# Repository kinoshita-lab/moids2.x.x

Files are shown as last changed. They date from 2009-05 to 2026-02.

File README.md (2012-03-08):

# About
These files are schematics, frame designs, and source codes for an artwork "moids 2.*.*".
You need at least arduino(pro, nano, duemilanove, etc.) or some alternatives to run this program.
We have confirmed this program works on Arduino-1.0 version so far.

When you want to know more about moids, please visit our website or watch video on youtube.

- http://www.moids.org/
- http://www.youtube.com/watch?v=-VmGS8YM7mo

# Instructions

1. get sources

   - git clone https://github.com/kinoshita-lab/moids-app.git

2. connect some devices, referring to the schematics

3. start Arduino environment, open moids_arduino.ino, verify and upload to I/O board.

4. repeat step 2 and 3 more than 400 times.

# Lisence

MsTimer2 library is a work by Javier Valencia, and has LGPL Lisence.

The others are completely public domain, 
You can modify, distribute as you like.

saita[at]kinoshita-lab.org

---
Kinoshita-lab 2009-2012

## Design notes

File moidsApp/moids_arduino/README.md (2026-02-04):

use arduino IDE with: 
Arduino Pro 3.3V 8MHz

pins

- LED 6, 9, 10
- Relay 4, 7, 8
- Mic A0, A1, A2

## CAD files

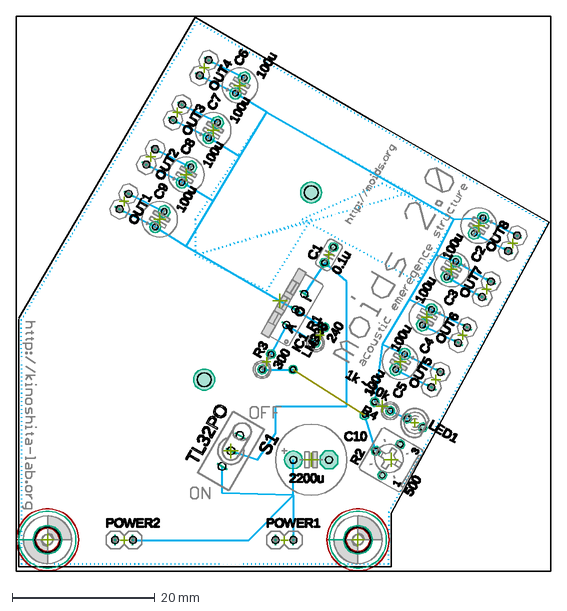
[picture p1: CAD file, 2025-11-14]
schematics/2025_power/graphics/moids2_0.1power_board_ほぼ原寸_all.dxf
75.0 x 77.9 mm

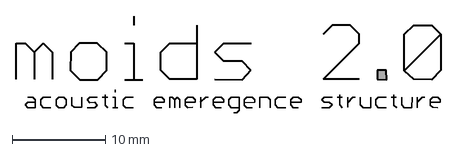
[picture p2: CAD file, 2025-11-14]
schematics/2025_power/moids2_0_text.dxf
45.4 x 10.3 mm

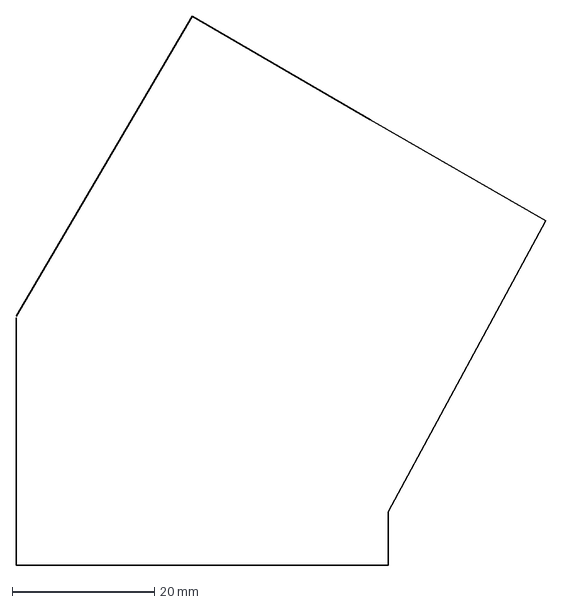
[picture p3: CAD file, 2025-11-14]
schematics/2025_power/graphics/moids2_0.1power_board_ほぼ原寸_edge_cuts.dxf
74.4 x 77.1 mm

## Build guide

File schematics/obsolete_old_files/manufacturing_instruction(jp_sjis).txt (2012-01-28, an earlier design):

moids2_0.1power.cmp(部品面パターンデータ)
moids2_0.1power.gpi（レポートファイル)
moids2_0.1power.plc（部品面シルクデータ）
moids2_0.1power.sol（半田面パターンデータ）
moids2_0.1power.stc（部品面レジストデータ）
moids2_0.1power.sts（半田面レジストデータ）
moids2_0.1power.out（外形線データ）

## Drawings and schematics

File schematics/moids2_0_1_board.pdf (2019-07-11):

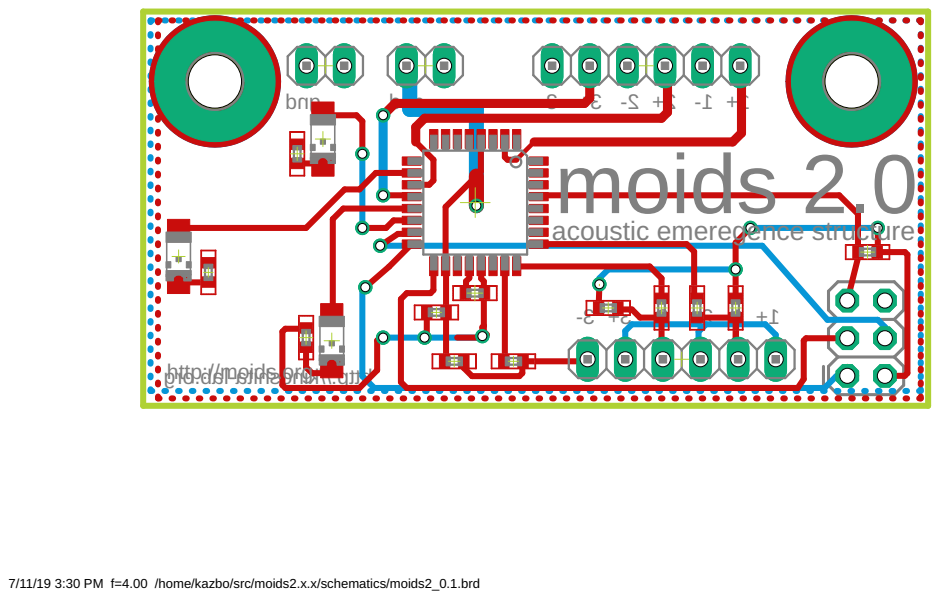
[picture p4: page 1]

7/11/19 3:30 PM f=4.00 /home/kazbo/src/moids2.x.x/schematics/moids2_0.1.brd

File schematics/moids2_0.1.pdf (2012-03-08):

# Moids 2.x Main Circuit

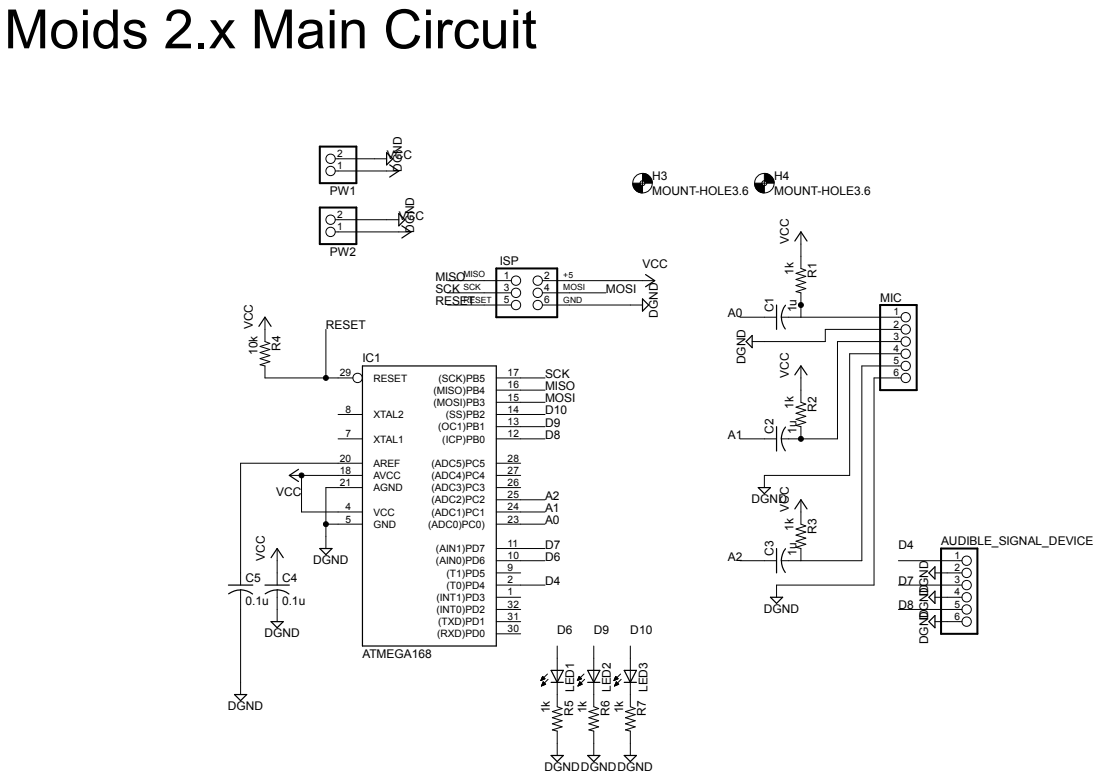
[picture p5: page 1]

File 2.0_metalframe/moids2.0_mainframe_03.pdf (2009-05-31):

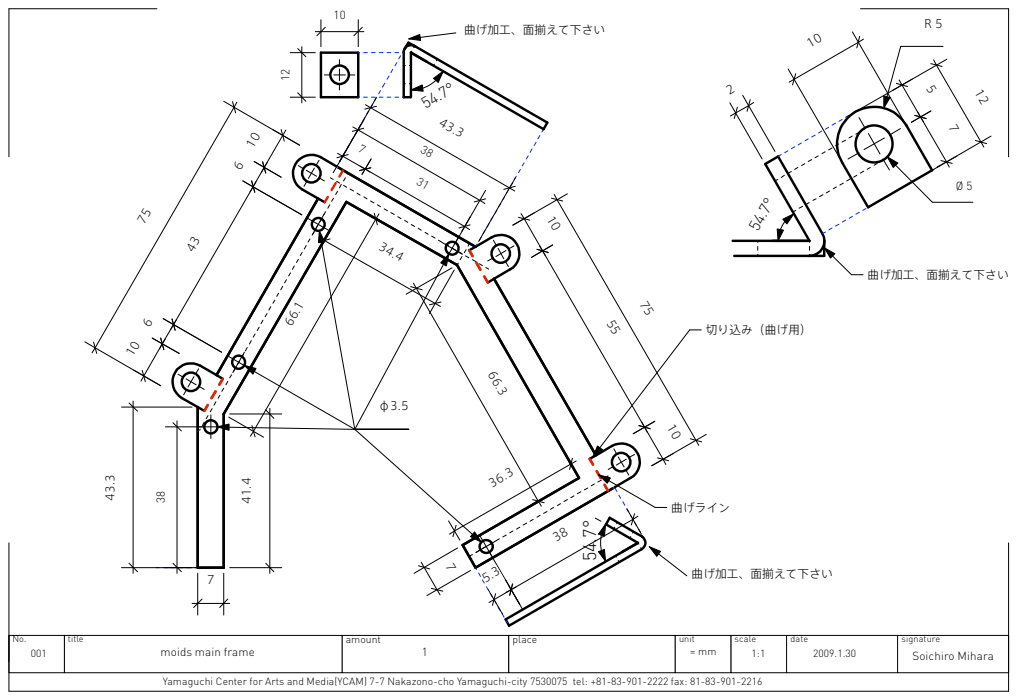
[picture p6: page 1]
title; amount; place; unit; scale; date; signature; Soichiro Mihara moids main frame; 曲げライン; 切り込み（曲げ用）; 曲げ加工、面揃えて下さい

Yamaguchi Center for Arts and Media(YCAM) 7-7 Nakazono-cho Yamaguchi-city 7530075 tel: +81-83-901-2222 fax: 81-83-901-2216

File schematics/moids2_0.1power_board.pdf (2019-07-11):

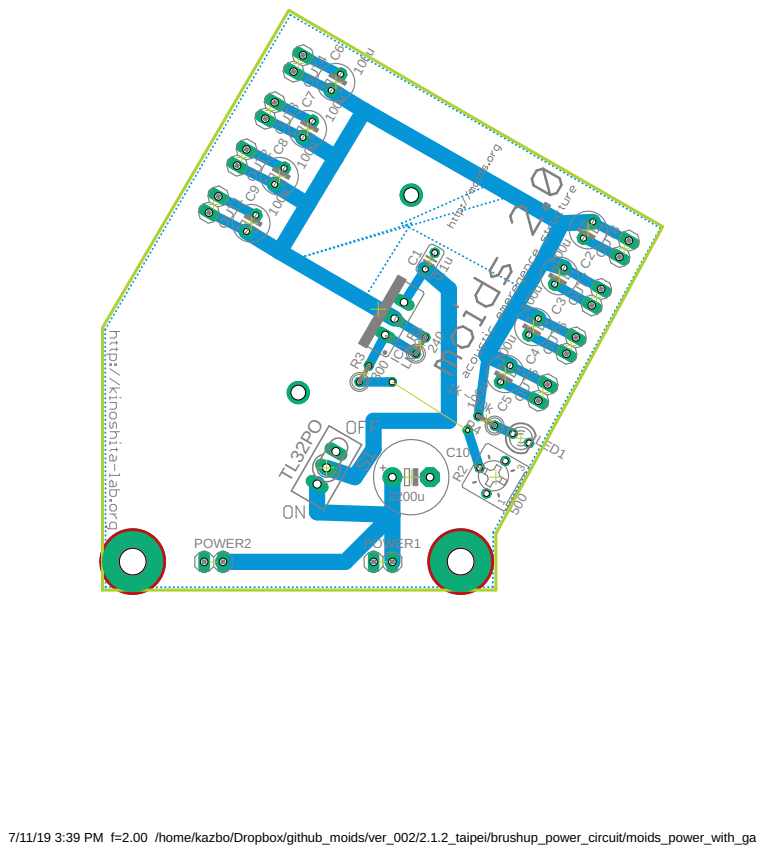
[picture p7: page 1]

7/11/19 3:39 PM f=2.00 /home/kazbo/Dropbox/github_moids/ver_002/2.1.2_taipei/brushup_power_circuit/moids_power_with_garbar/moids2_0.1power.brd

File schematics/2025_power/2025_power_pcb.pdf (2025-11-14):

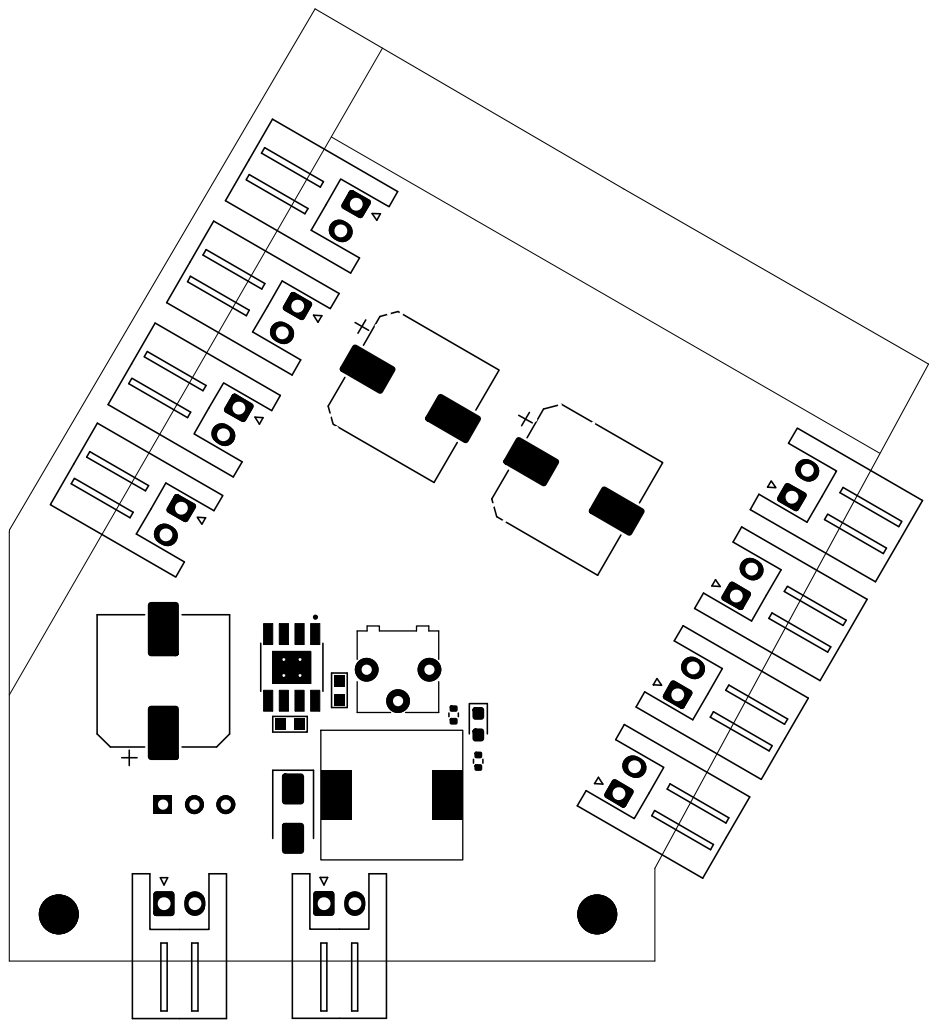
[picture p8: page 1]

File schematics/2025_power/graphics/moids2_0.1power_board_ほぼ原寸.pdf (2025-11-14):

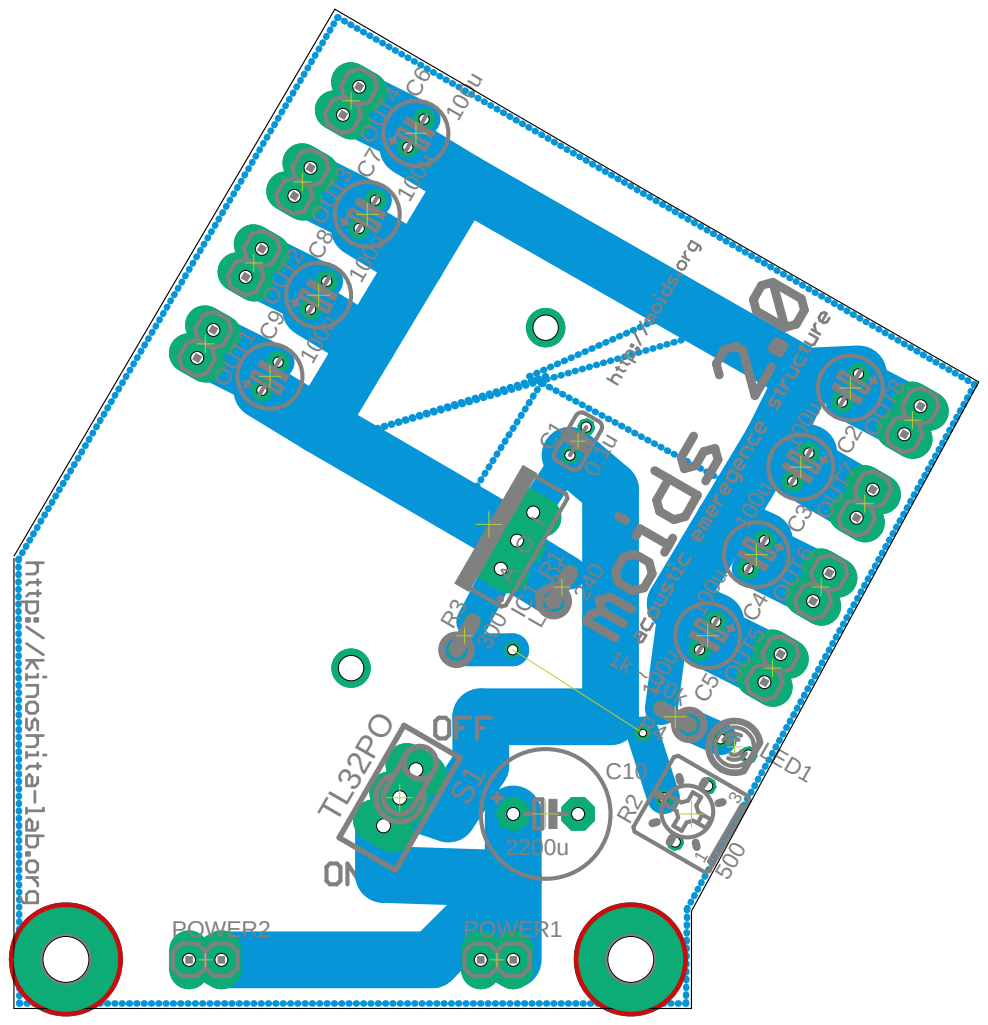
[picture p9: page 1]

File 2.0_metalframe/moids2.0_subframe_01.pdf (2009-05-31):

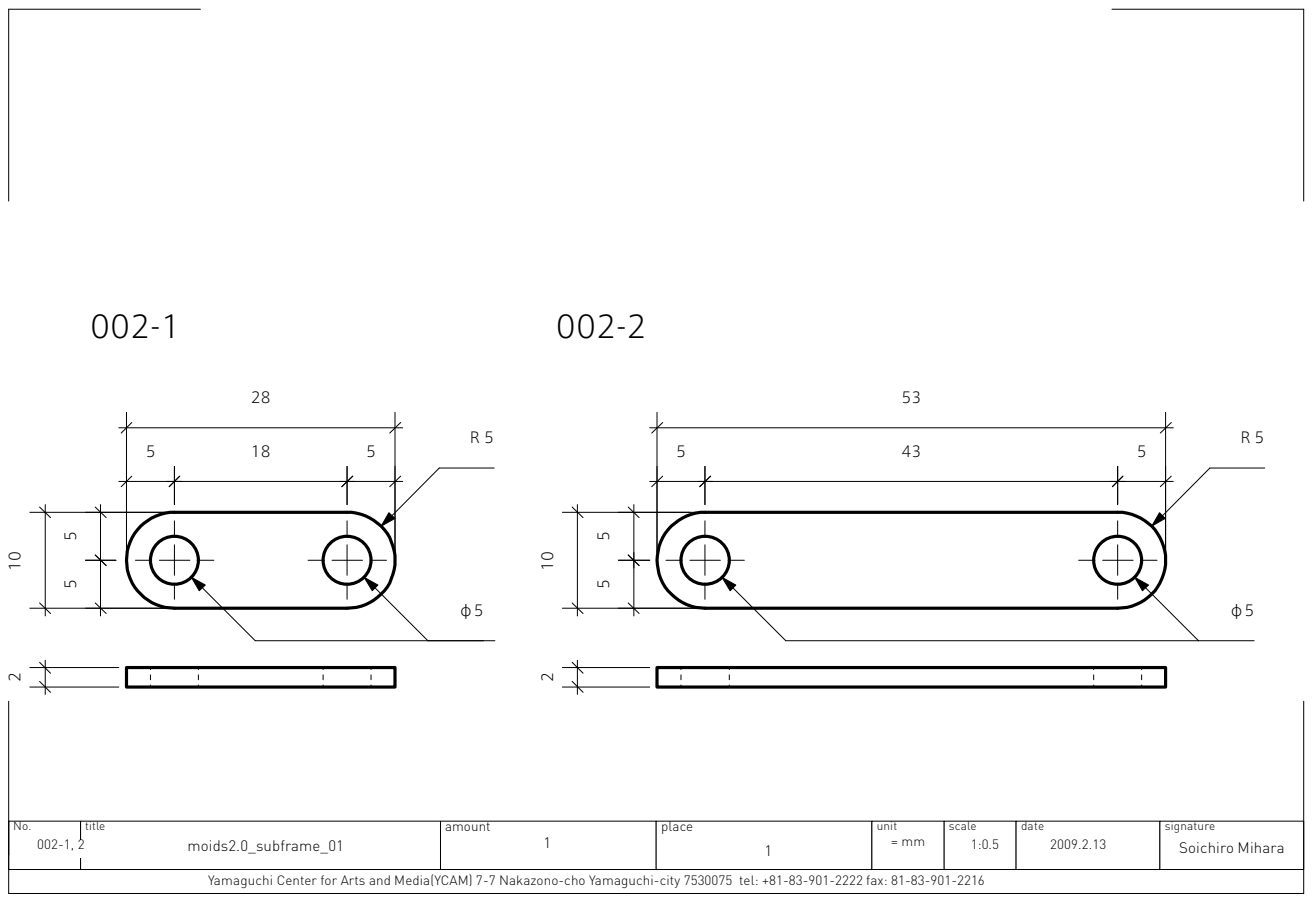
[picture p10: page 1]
title; amount; place; unit; scale; date; signature; Soichiro Mihara moids2.0_subframe_01

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

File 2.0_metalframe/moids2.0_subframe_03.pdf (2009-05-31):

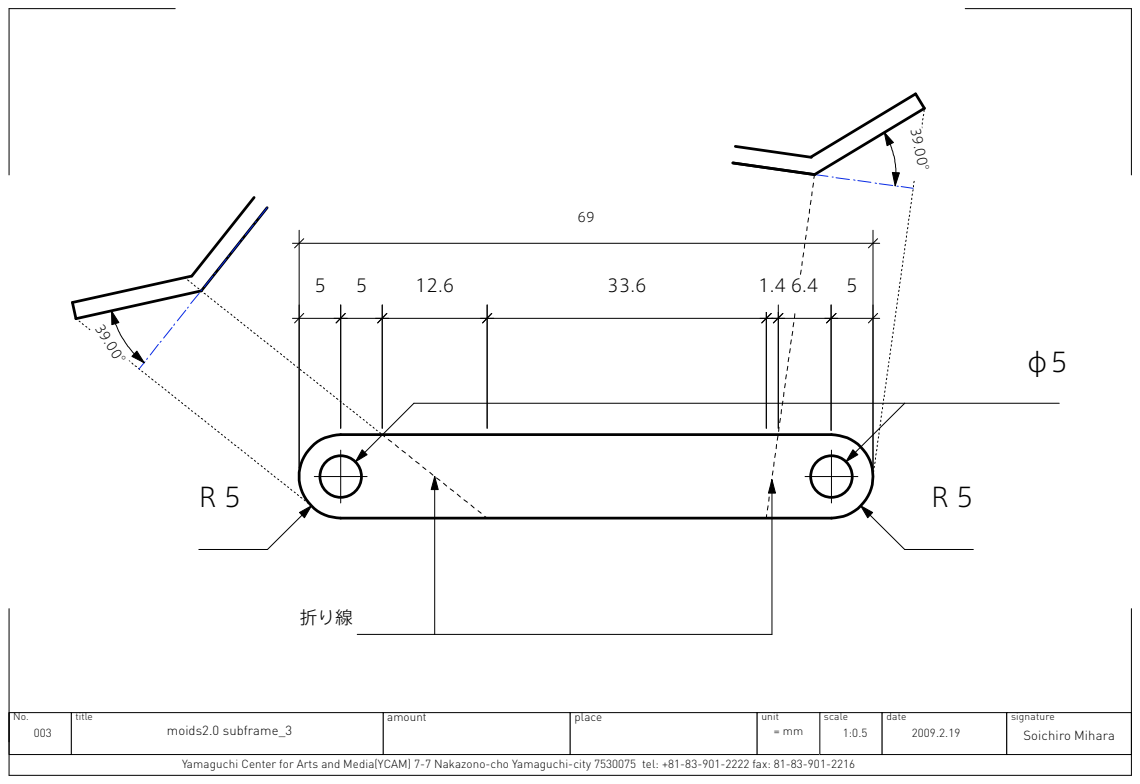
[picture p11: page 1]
title; amount; place; unit; scale; date; signature; moids2.0; Soichiro Mihara subframe_3; 折り線

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

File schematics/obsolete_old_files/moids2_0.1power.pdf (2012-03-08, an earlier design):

# Moids 2.x Power Circuit

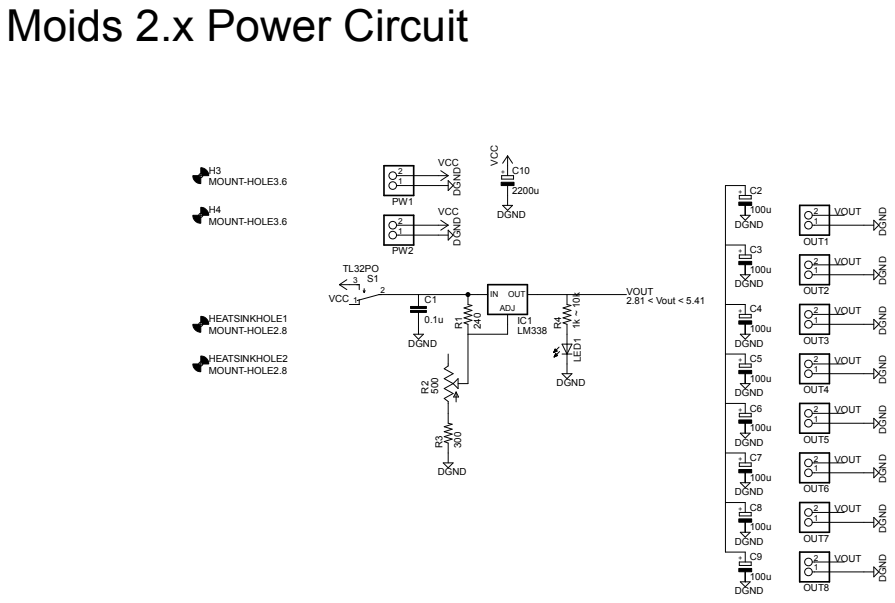
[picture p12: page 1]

DGNDDGND DGNDDGND

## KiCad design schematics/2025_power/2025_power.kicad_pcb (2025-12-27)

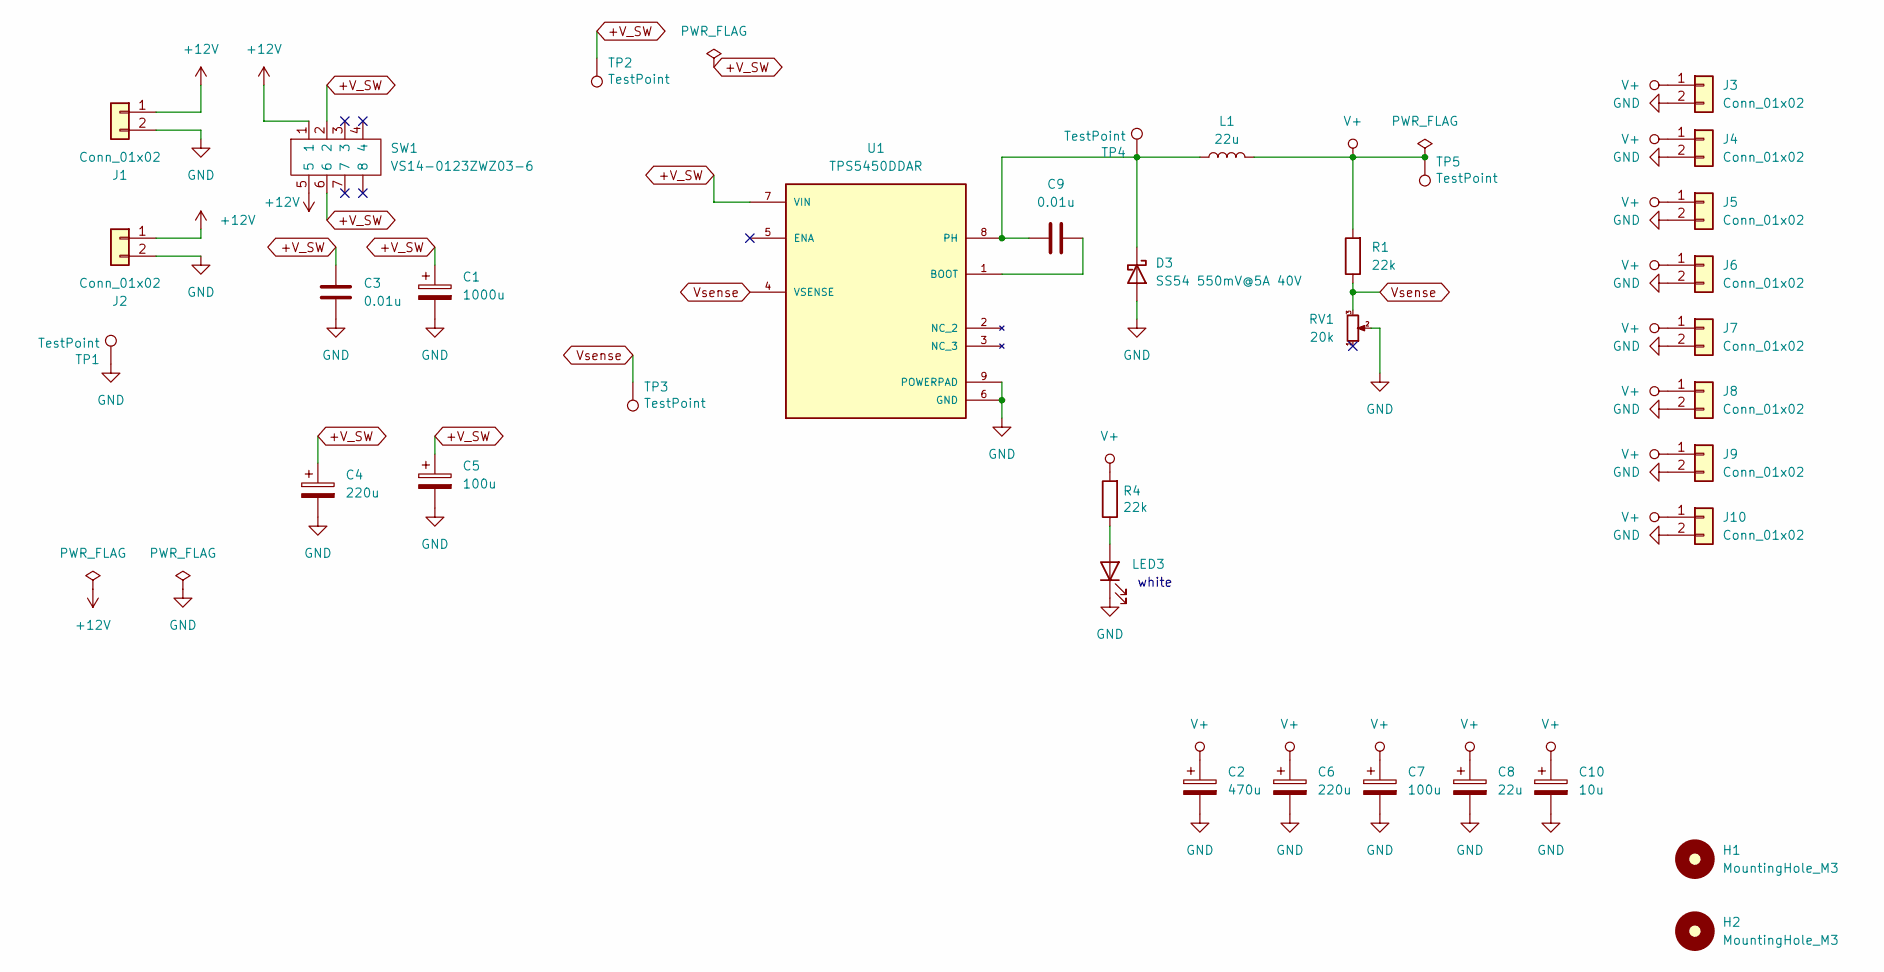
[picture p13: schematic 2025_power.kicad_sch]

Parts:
C1: 1000u; CP_Elec_10x10.5; LCSC C46550395
C2: 470u; CP_Elec_10x10; LCSC C3350
C3, C9: 0.01u; C0603; LCSC C57112
C4, C6: 220u; CP_Elec_6.3x7.7; LCSC C2918361
C5, C7: 100u; CP_Elec_6.3x7.7; LCSC C72478
C8: 22u; CP_Elec_6.3x5.4; LCSC C72505
C10: 10u; CP_Elec_4x5.4; LCSC C72485
D3: SS54 550mV@5A 40V; D_SMA; LCSC C727065
H1, H2: MountingHole_M3; MountingHole_3.2mm_M3
J1, J2: Conn_01x02; JST_VH_B2PS-VH_1x02_P3.96mm_Horizontal; LCSC C158007
J3, J4, J5, J6, J7, J8, J9, J10: Conn_01x02; JST_XH_B2B-XH-A_1x02_P2.50mm_Vertical; LCSC C158012
L1: 22u; Inductor_SMD_11.5x10.5; LCSC C22463844
LED3: 19-217/GHC-YR1S2/3T; LED_0603_1608Metric_Pad1.05x0.95mm_HandSolder; LCSC C2290
R1, R4: 22k; R_0402_1005Metric; LCSC C25547
RV1: 20k; Potentiometer_Bourns_3314J_Vertical; LCSC C55069
SW1: VS14-0123ZWZ03-6; Legion VS14-0123ZWZ03-6; LCSC C5186986
TP1, TP2, TP3, TP4, TP5: TestPoint; TP_1PAD
U1: TPS5450DDAR; CONV_TPS5450DDAR; PARTREV D; LCSC C114425

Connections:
+12V: J1.1, J2.1, SW1.1, SW1.5
+V_SW: C1.1, C3.2, C4.1, C5.1, SW1.2, SW1.6, TP2.1, U1.7 (VIN)
GND: C1.2, C2.2, C3.1, C4.2, C5.2, C6.2, C7.2, C8.2, C10.2, D3.2 (A), J1.2, J2.2, J3.2, J4.2, J5.2, J6.2, J7.2, J8.2, J9.2, J10.2, LED3.1 (K), RV1.2, TP1.1, U1.6 (GND), U1.9 (POWERPAD)
unnamed: C9.1, D3.1 (K), L1.1, TP4.1, U1.8 (PH)
unnamed: LED3.2 (A), R4.1
unnamed: C9.2, U1.1 (BOOT)
V+: C2.1, C6.1, C7.1, C8.1, C10.1, J3.1, J4.1, J5.1, J6.1, J7.1, J8.1, J9.1, J10.1, L1.2, R1.2, R4.2, TP5.1
Vsense: R1.1, RV1.3, TP3.1, U1.4 (VSENSE)

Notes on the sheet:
white

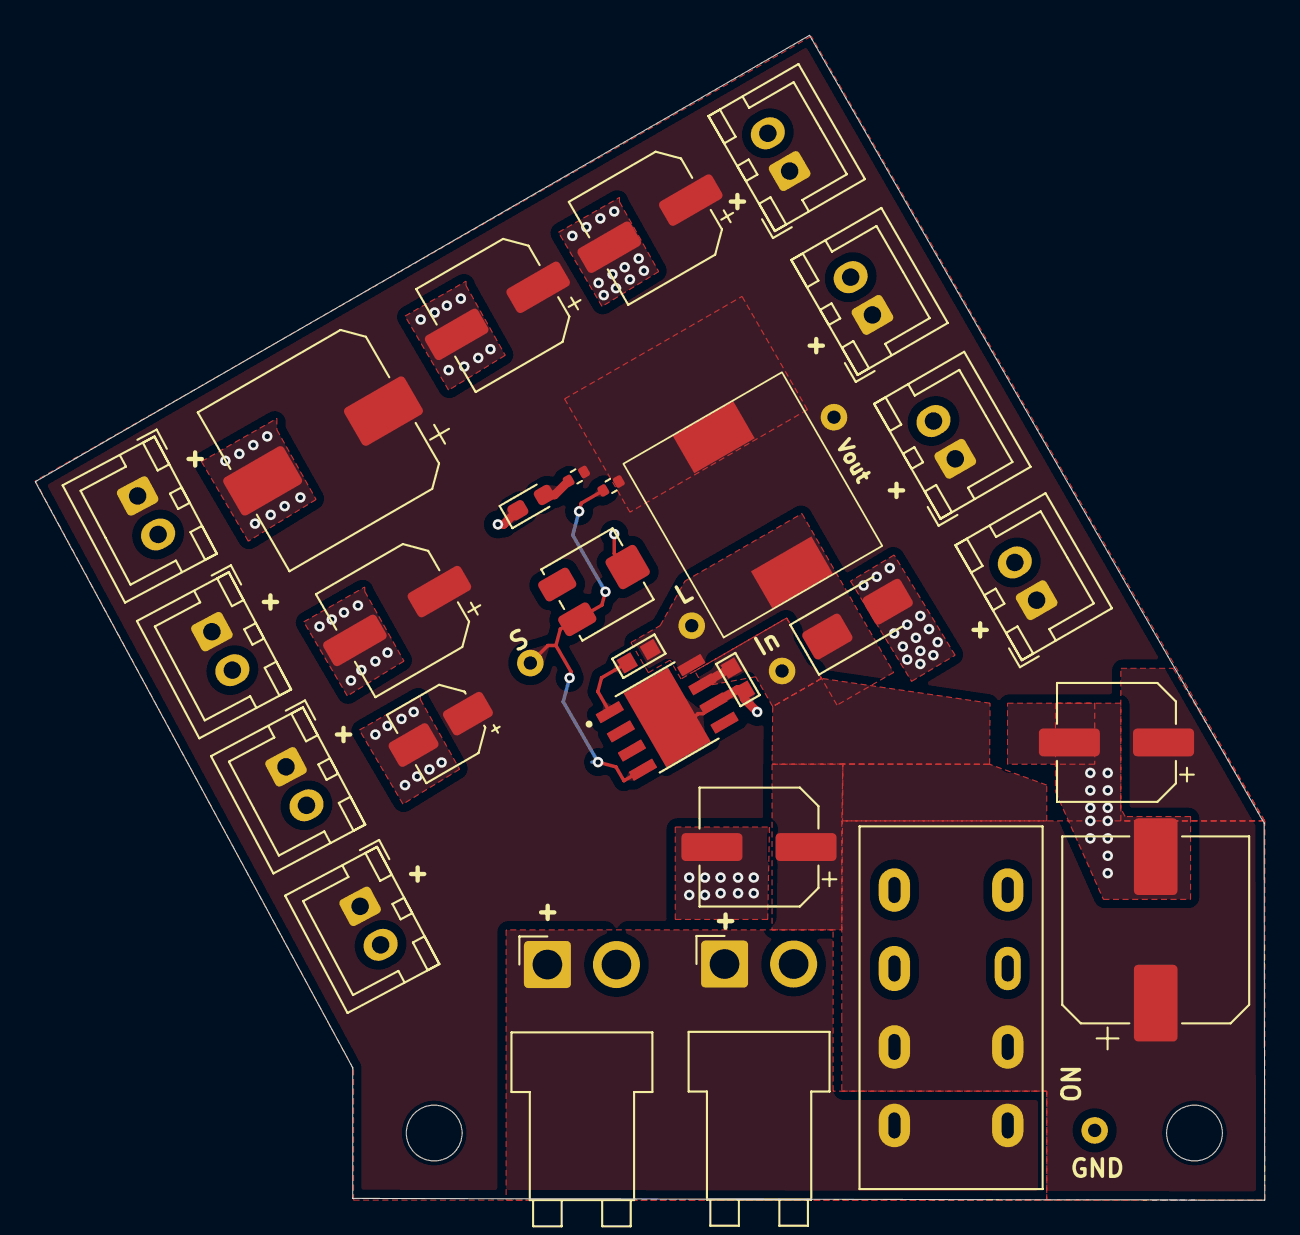
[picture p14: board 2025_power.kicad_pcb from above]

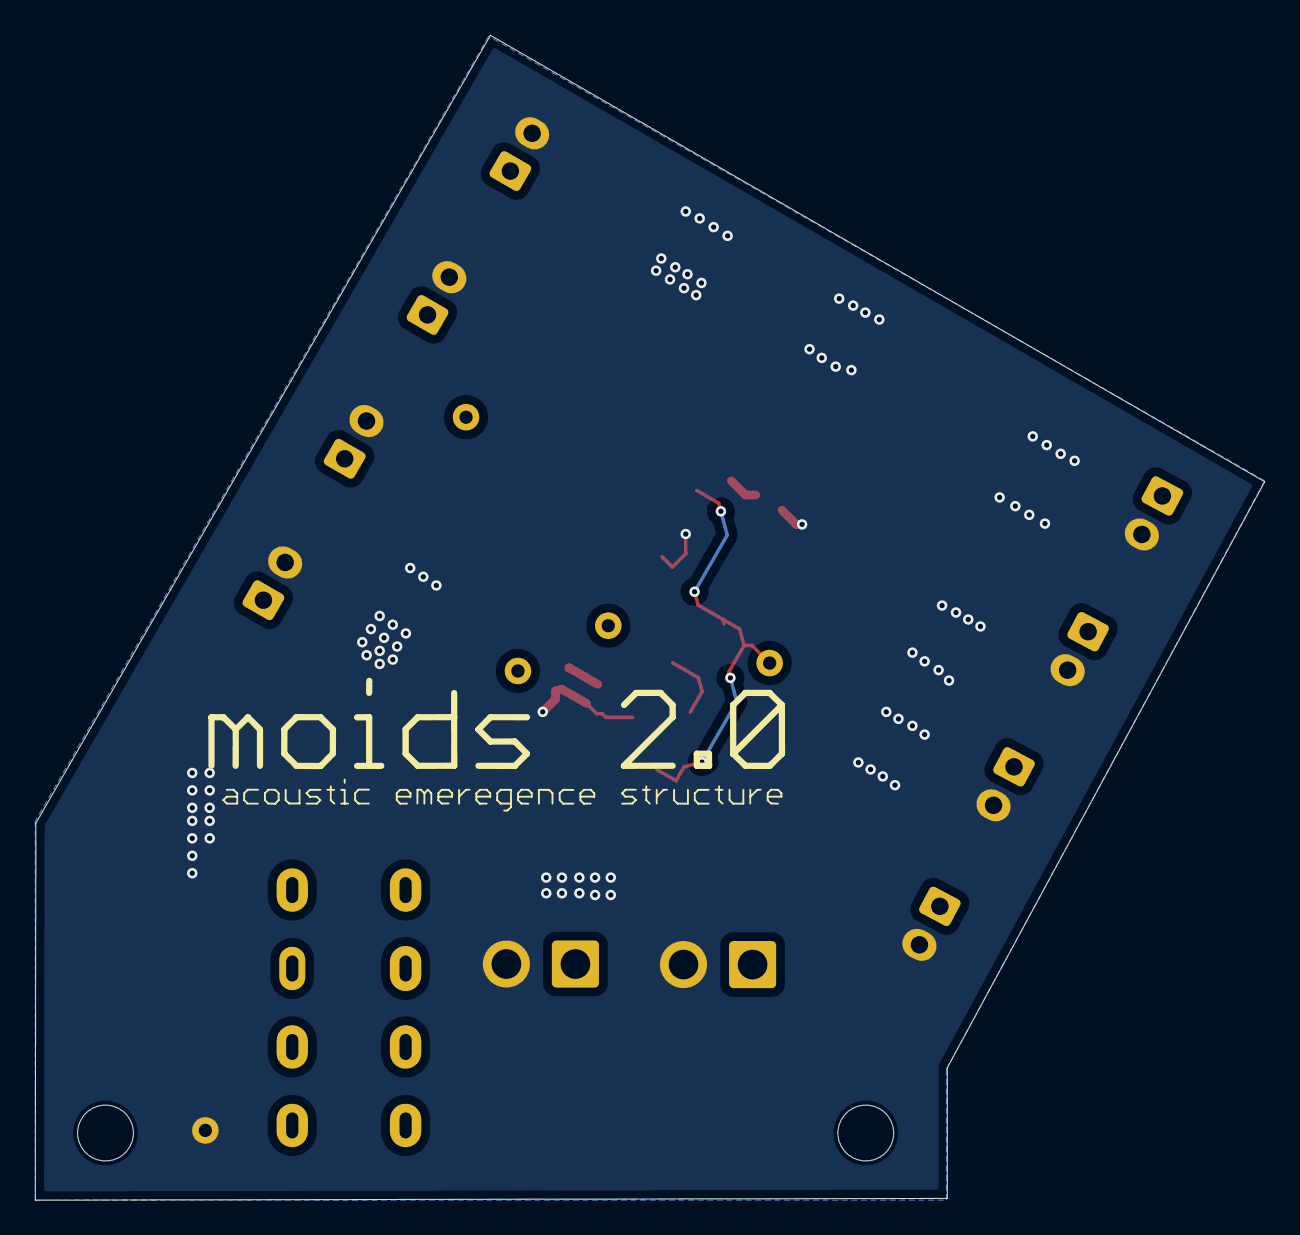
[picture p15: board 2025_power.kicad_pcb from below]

Board: 2 copper layers, 70.5 x 66.8 mm, 35 parts (3 on the bottom side), 8 nets.

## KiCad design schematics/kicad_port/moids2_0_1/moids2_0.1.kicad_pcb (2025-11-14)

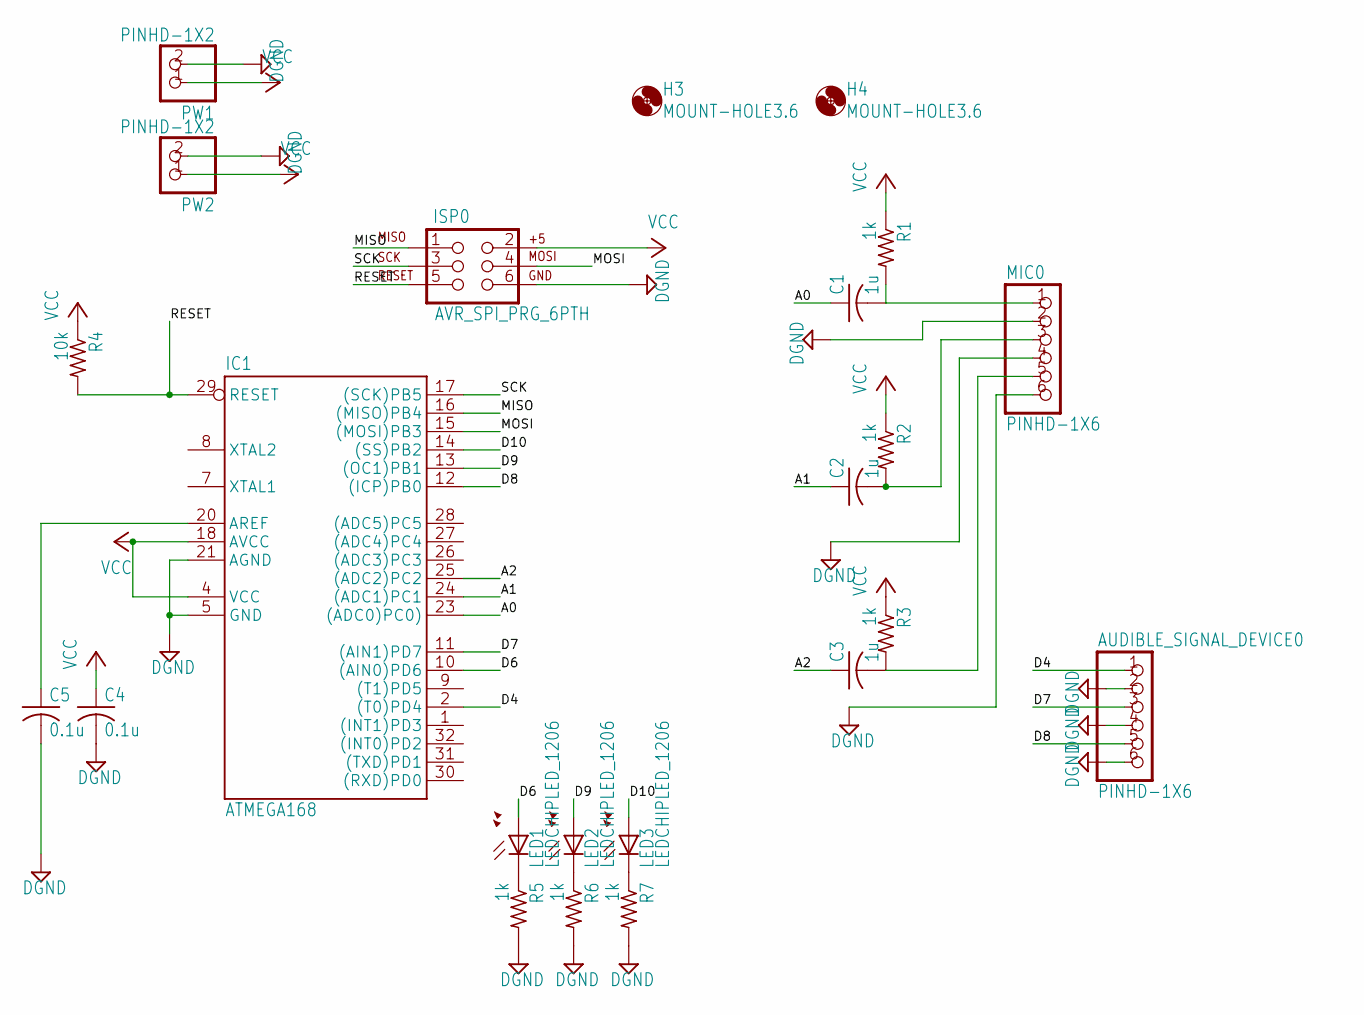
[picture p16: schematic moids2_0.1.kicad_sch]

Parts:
AUDIBLE_SIGNAL_DEVICE0: PINHD-1X6; 1X06
C1, C2, C3: 1u; C1005
C4, C5: 0.1u; C1005
H3, H4: MOUNT-HOLE3.6; 3,6
IC1: ATMEGA168; TQFP32-08
ISP0: AVR_SPI_PRG_6PTH; 2X3
LED1, LED2, LED3: LEDCHIPLED_1206; CHIPLED_1206
MIC0: PINHD-1X6; 1X06
PW1, PW2: PINHD-1X2; 1X02
R1, R2, R3, R5, R6, R7: 1k; R1005
R4: 10k; R1005

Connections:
A0: C1.1, IC1.23 ((ADC0)PC0))
A1: C2.1, IC1.24 ((ADC1)PC1)
A2: C3.1, IC1.25 ((ADC2)PC2)
AREF: C5.1, IC1.20 (AREF)
D4: AUDIBLE_SIGNAL_DEVICE0.1, IC1.2 ((T0)PD4)
D6: IC1.10 ((AIN0)PD6), LED1.A
D7: AUDIBLE_SIGNAL_DEVICE0.3, IC1.11 ((AIN1)PD7)
D8: AUDIBLE_SIGNAL_DEVICE0.5, IC1.12 ((ICP)PB0)
D9: IC1.13 ((OC1)PB1), LED2.A
D10: IC1.14 ((SS)PB2), LED3.A
DGND: AUDIBLE_SIGNAL_DEVICE0.2, AUDIBLE_SIGNAL_DEVICE0.4, AUDIBLE_SIGNAL_DEVICE0.6, C4.2, C5.2, IC1.5 (GND), IC1.21 (AGND), ISP0.6, MIC0.2, MIC0.4, MIC0.6, PW1.2, PW2.2, R5.2, R6.2, R7.2
MISO: IC1.16 ((MISO)PB4), ISP0.1
MOSI: IC1.15 ((MOSI)PB3), ISP0.4
unnamed: C1.2, MIC0.1, R1.2
unnamed: C2.2, MIC0.3, R2.2
unnamed: C3.2, MIC0.5, R3.2
unnamed: LED1.C, R5.1
unnamed: LED2.C, R6.1
unnamed: LED3.C, R7.1
RESET: IC1.29 (RESET), ISP0.5, R4.2
SCK: IC1.17 ((SCK)PB5), ISP0.3
VCC: C4.1, IC1.4 (VCC), IC1.18 (AVCC), ISP0.2, PW1.1, PW2.1, R1.1, R2.1, R3.1, R4.1

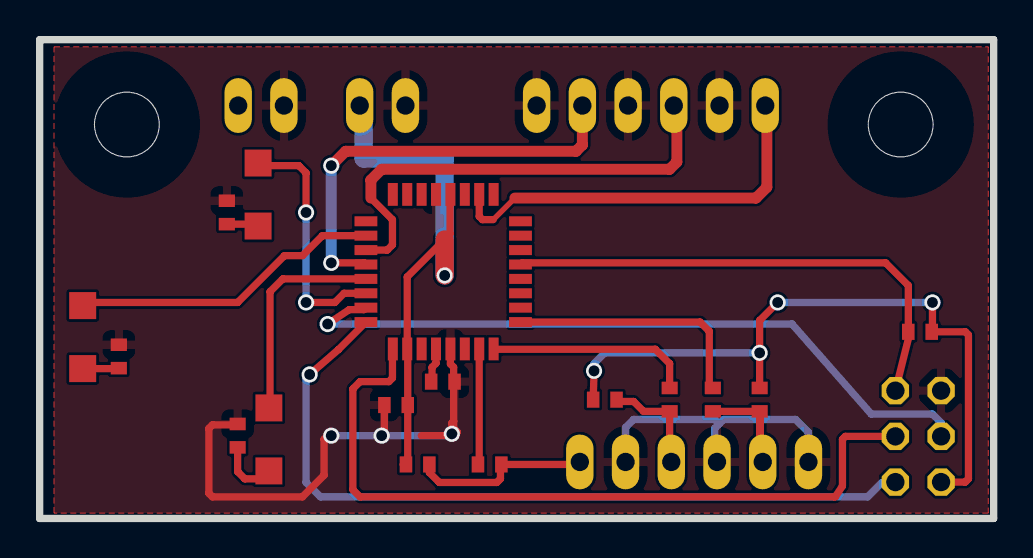
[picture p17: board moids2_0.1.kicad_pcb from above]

Board: 2 copper layers, 53.0 x 26.6 mm, 23 parts (1 on the bottom side), 22 nets.

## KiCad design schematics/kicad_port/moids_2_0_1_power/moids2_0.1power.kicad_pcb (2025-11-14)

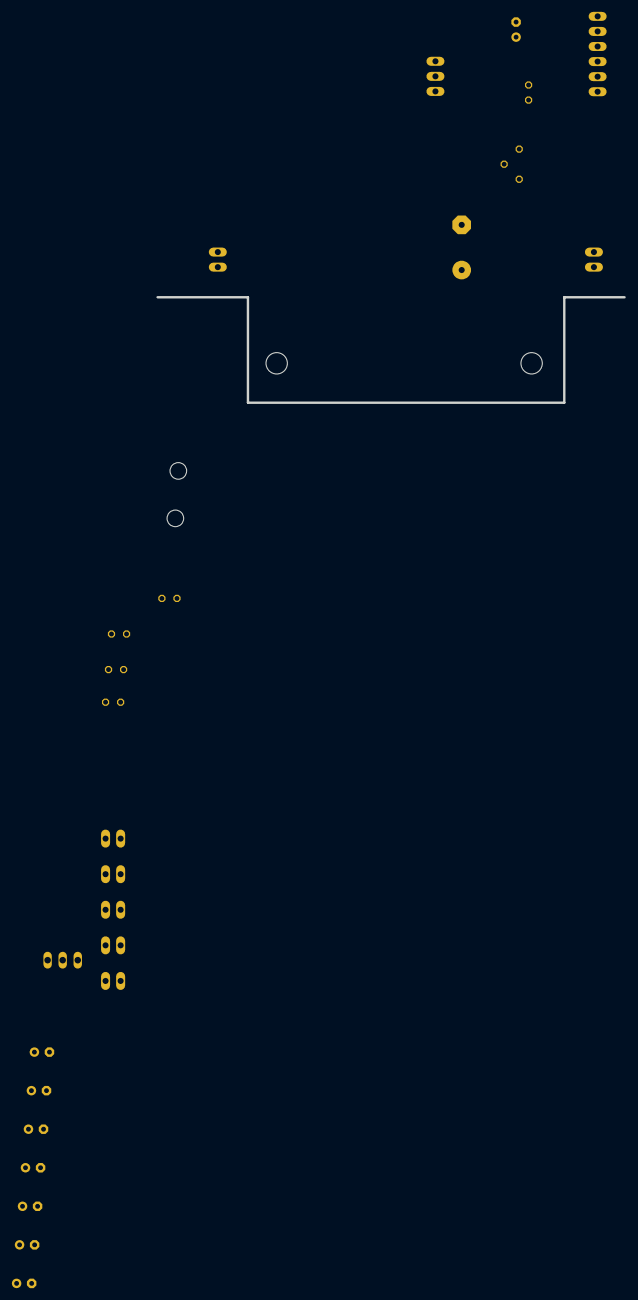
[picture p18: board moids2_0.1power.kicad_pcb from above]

Board: 2 copper layers, 31 parts (0 on the bottom side), 7 nets, no tracks yet.

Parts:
C1: 0.1u; C025-024X044
C2, C3, C4, C5, C6, C7, C8, C9: 100u; E2,5-5
C10: 2200u; E7,5-16
H3, H4: MOUNT-HOLE3.6; 3,6
HEATSINKHOLE1, HEATSINKHOLE2: MOUNT-HOLE2.8; 2,8
IC1: LM338; 317TS
LED1: LED3MM
OUT1, OUT2, OUT3, OUT4, OUT5, OUT6, OUT7, OUT8: 1X02
PW1, PW2: 1X02
R1: 240; 0207_2V
R2: 500; B25P
R3: 300; 0207_2V
R4: 1k ~ 10k; 0207_2V
S1: TL32PO; TL3XPO

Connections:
DGND: C1.2, C2.-, C3.-, C4.-, C5.-, C6.-, C7.-, C8.-, C9.-, C10.-, LED1.K, OUT1.1, OUT2.1, OUT3.1, OUT4.1, OUT5.1, OUT6.1, OUT7.1, OUT8.1, PW1.1, PW2.1, R3.1
unnamed: IC1.1, R1.1, R2.S
unnamed: R2.A, R3.2
unnamed: LED1.A, R4.1
VCC: C10.+, PW1.2, PW2.2, S1.3
VIN: C1.1, IC1.3, R1.2, S1.2
VOUT: C2.+, C3.+, C4.+, C5.+, C6.+, C7.+, C8.+, C9.+, IC1.2, OUT1.2, OUT2.2, OUT3.2, OUT4.2, OUT5.2, OUT6.2, OUT7.2, OUT8.2, R4.2

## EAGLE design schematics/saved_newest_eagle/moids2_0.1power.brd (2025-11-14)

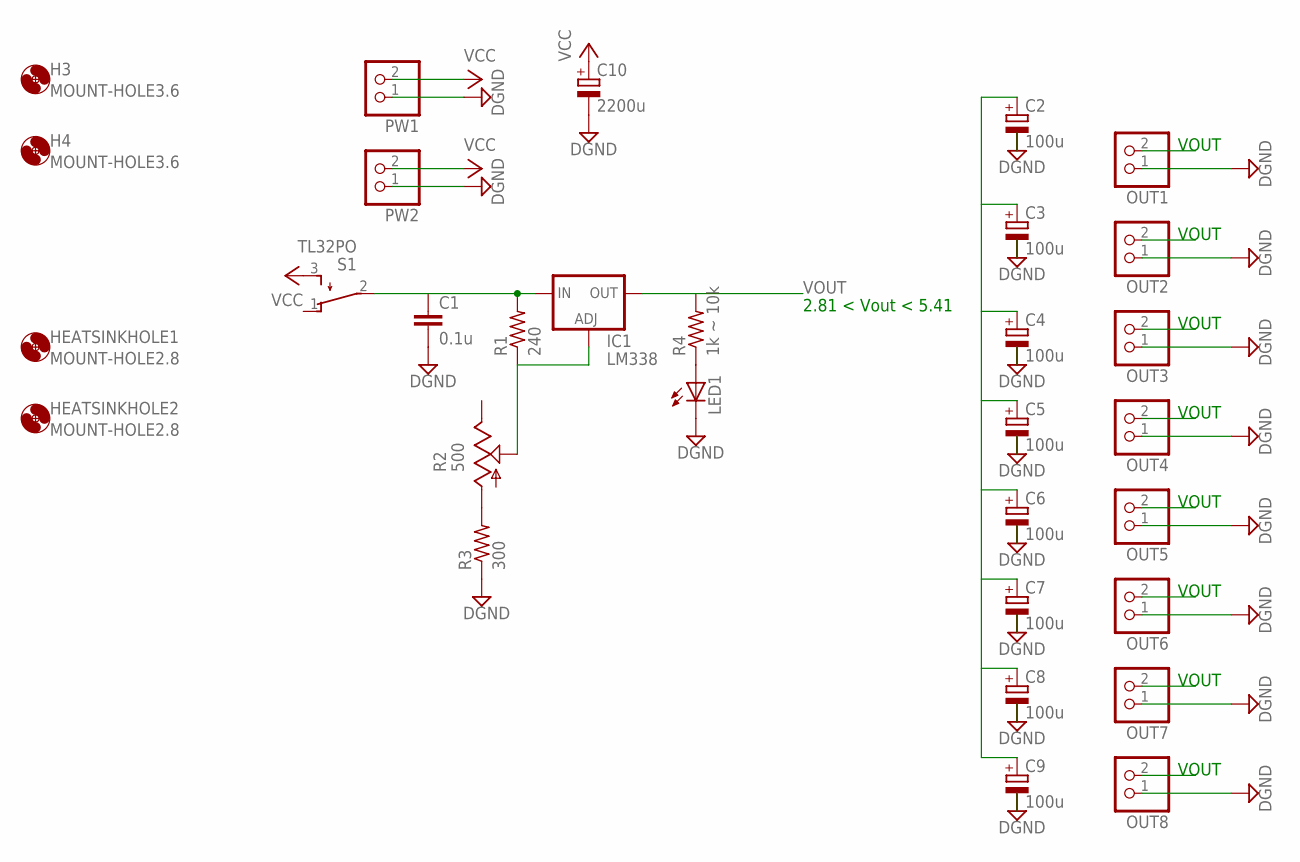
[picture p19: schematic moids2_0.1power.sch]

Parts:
C1: 0.1u; C025-024X044
C2, C3, C4, C5, C6, C7, C8, C9: 100u; E2,5-5
C10: 2200u; E7,5-16
H3, H4: MOUNT-HOLE3.6; 3,6
HEATSINKHOLE1, HEATSINKHOLE2: MOUNT-HOLE2.8; 2,8
IC1: LM338; 317TS
LED1: LED3MM
OUT1, OUT2, OUT3, OUT4, OUT5, OUT6, OUT7, OUT8: PINHD-1X2; 1X02
PW1, PW2: PINHD-1X2; 1X02
R1: 240; 0207/2V
R2: 500; B25P
R3: 300; 0207/2V
R4: 1k ~ 10k; 0207/2V
S1: TL32PO; TL3XPO

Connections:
DGND: C1.2, C2.-, C3.-, C4.-, C5.-, C6.-, C7.-, C8.-, C9.-, C10.-, LED1.K (C), OUT1.1, OUT2.1, OUT3.1, OUT4.1, OUT5.1, OUT6.1, OUT7.1, OUT8.1, PW1.1, PW2.1, R3.1
unnamed: IC1.1 (ADJ), R1.1, R2.S
unnamed: R2.A, R3.2
unnamed: LED1.A, R4.1
VCC: C10.+, PW1.2, PW2.2, S1.3 (S)
VIN: C1.1, IC1.3 (IN), R1.2, S1.2
VOUT: C2.+, C3.+, C4.+, C5.+, C6.+, C7.+, C8.+, C9.+, IC1.2 (OUT), OUT1.2, OUT2.2, OUT3.2, OUT4.2, OUT5.2, OUT6.2, OUT7.2, OUT8.2, R4.2

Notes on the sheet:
2.81 < Vout < 5.41
VOUT

Board: 2 copper layers, 31 parts (0 on the bottom side), 7 nets, no tracks yet.

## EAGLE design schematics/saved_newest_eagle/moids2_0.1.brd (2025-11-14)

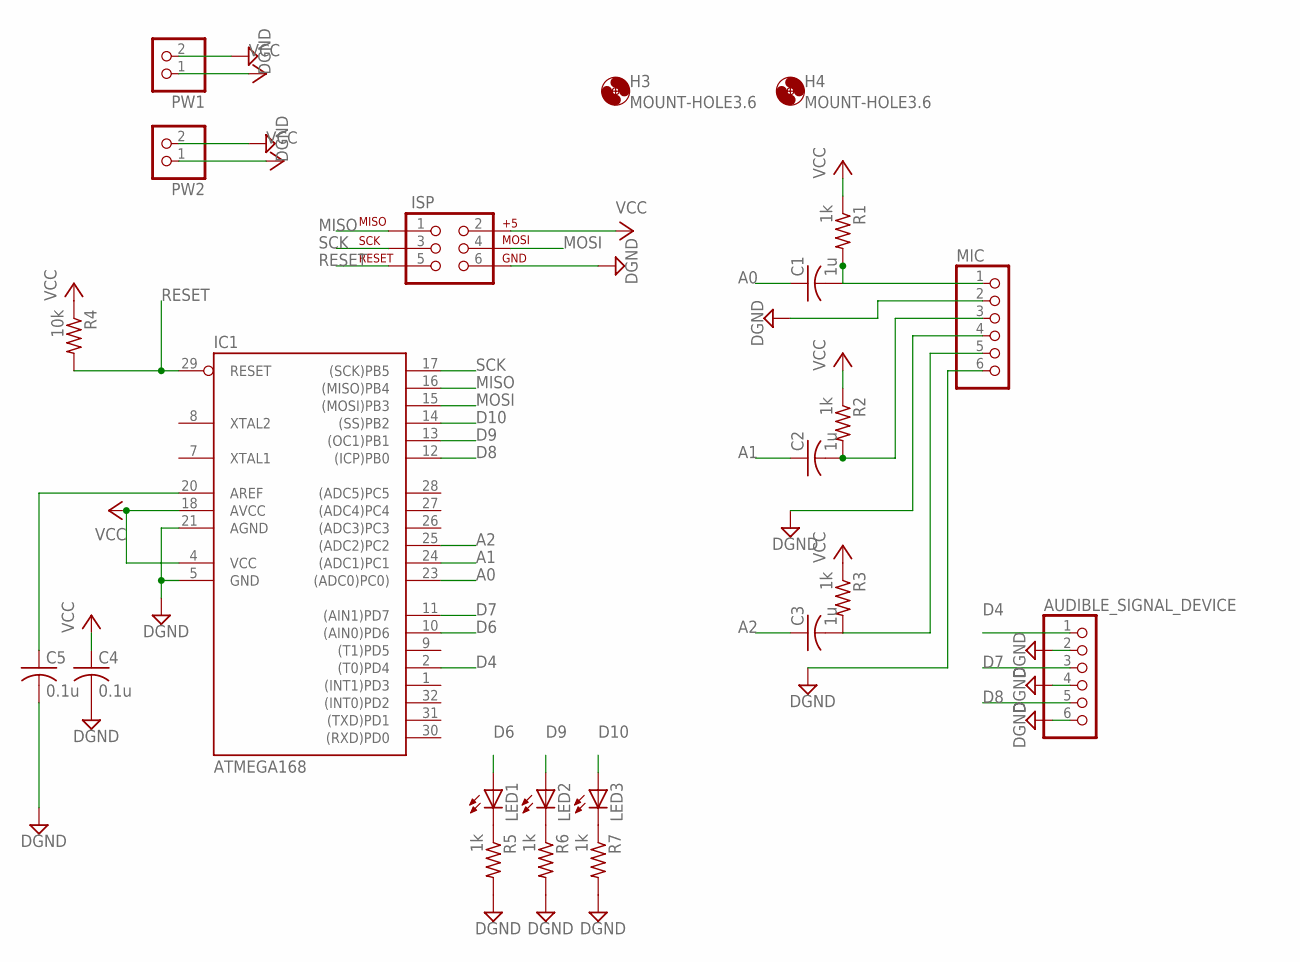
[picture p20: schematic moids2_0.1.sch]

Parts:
AUDIBLE_SIGNAL_DEVICE: PINHD-1X6; 1X06
C1, C2, C3: 1u; C1005
C4, C5: 0.1u; C1005
H3, H4: MOUNT-HOLE3.6; 3,6
IC1: ATMEGA168; TQFP32-08
ISP: AVR_SPI_PRG_6PTH; 2X3
LED1, LED2, LED3: LEDCHIPLED_1206; CHIPLED_1206
MIC: PINHD-1X6; 1X06
PW1, PW2: PINHD-1X2; 1X02
R1, R2, R3, R5, R6, R7: 1k; R1005
R4: 10k; R1005

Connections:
A0: C1.1, IC1.23 ((ADC0)PC0))
A1: C2.1, IC1.24 ((ADC1)PC1)
A2: C3.1, IC1.25 ((ADC2)PC2)
AREF: C5.1, IC1.20 (AREF)
D4: AUDIBLE_SIGNAL_DEVICE.1, IC1.2 ((T0)PD4)
D6: IC1.10 ((AIN0)PD6), LED1.A
D7: AUDIBLE_SIGNAL_DEVICE.3, IC1.11 ((AIN1)PD7)
D8: AUDIBLE_SIGNAL_DEVICE.5, IC1.12 ((ICP)PB0)
D9: IC1.13 ((OC1)PB1), LED2.A
D10: IC1.14 ((SS)PB2), LED3.A
DGND: AUDIBLE_SIGNAL_DEVICE.2, AUDIBLE_SIGNAL_DEVICE.4, AUDIBLE_SIGNAL_DEVICE.6, C4.2, C5.2, IC1.5 (GND), IC1.21 (AGND), ISP.6, MIC.2, MIC.4, MIC.6, PW1.2, PW2.2, R5.2, R6.2, R7.2
MISO: IC1.16 ((MISO)PB4), ISP.1
MOSI: IC1.15 ((MOSI)PB3), ISP.4
unnamed: C1.2, MIC.1, R1.2
unnamed: C2.2, MIC.3, R2.2
unnamed: C3.2, MIC.5, R3.2
unnamed: LED1.C, R5.1
unnamed: LED2.C, R6.1
unnamed: LED3.C, R7.1
RESET: IC1.29 (RESET), ISP.5, R4.2
SCK: IC1.17 ((SCK)PB5), ISP.3
VCC: C4.1, IC1.4 (VCC), IC1.18 (AVCC), ISP.2, PW1.1, PW2.1, R1.1, R2.1, R3.1, R4.1

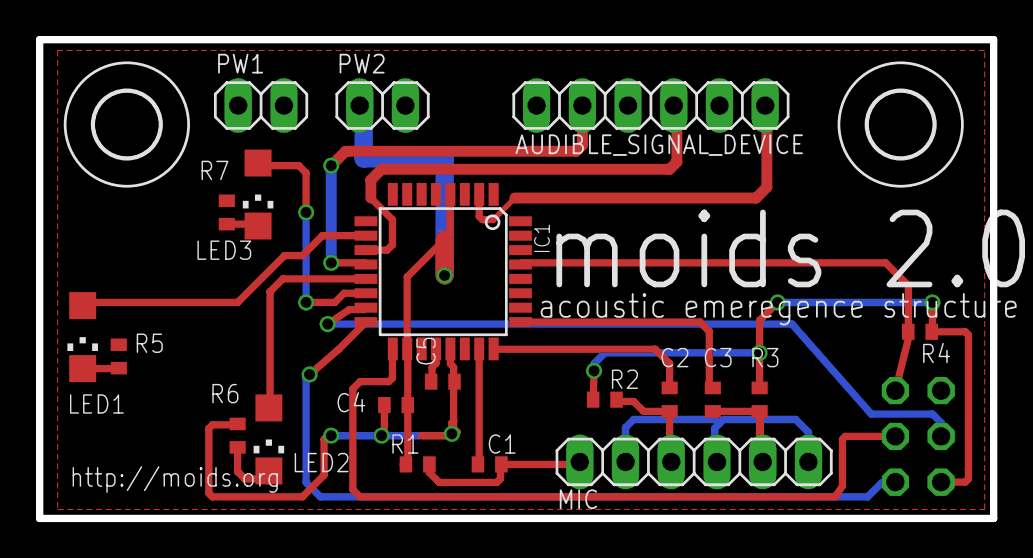
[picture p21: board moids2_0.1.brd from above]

Board: 2 copper layers, 53.0 x 26.6 mm, 23 parts (1 on the bottom side), 22 nets.

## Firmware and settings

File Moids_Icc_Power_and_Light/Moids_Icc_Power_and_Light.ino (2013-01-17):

#include <Arduino.h>
#include <stdint.h>
#include "DmxSimple.h"
#include "TimerOne.h"

struct BrightnessInfoTableItem
{
	uint8_t initialBrightness; // 最初の明るさ
	uint8_t lastBrightness; // 最後の明るさ
	uint32_t duration; // その間を移動する時間(msec)
};

// #define DEBUG

// このへんでいろんな設定ができる
static const uint32_t MOIDS_ON_TIME_LENGTH = 15UL * 60UL; // 電源On時間の長さを secで！
static const uint32_t POWER_OFF_TIME_LENGTH = 15UL; /// Offになっている時間の長さ sec。
static const uint32_t MINIMUM_ON_OFF_ASSERT_DELAY_MSEC = 3000UL; // 確実に全部がOffしてResetできるのに必要な時間(最低これ以上必要)
static const uint32_t NUMBER_OF_ON_OFF_TIMES = 2UL;

const int NUMBER_OF_BRIGHTNESS_TABLE_ITEM = 10; // 下の表の数
BrightnessInfoTableItem brightnessTable[NUMBER_OF_BRIGHTNESS_TABLE_ITEM] =
{
	{ 32, 64, 2UL * 1000UL }, // Offの時にだんだん明るくなる
	{ 64, 160, 1UL * 1000UL }, // Offの時にだんだん明るくなる
	{ 160, 140, 1UL * 1000UL }, // Offの時にだんだん明るくなる
	{ 140, 64, 60UL * 14UL * 1000UL }, // 定常状態 14分
	{ 64, 32, 50UL * 1000UL }, // 終わるときだんだん暗くなる

	{ 32, 64, 2UL * 1000UL }, // Offの時にだんだん明るくなる
	{ 64, 1, 1UL * 1000UL }, // Offの時にだんだん明るくなる
	{ 1, 128, 1UL * 1000UL }, // Offの時にだんだん明るくなる
	{ 128, 140, 60UL * 14UL * 1000UL }, // 定常状態 14分
	{ 140, 64, 50UL * 1000UL }, // 終わるときだんだん暗くなる
};

// このへんは基本的なPINの設定
static const int DMX_OUT_PIN = 8;
static const int DMX_CHANNEL = 1;
static const int POWER_CIRCUIT_MASTER_PIN = 5;
static const int NUMBER_OF_POWER_CIRCUITS = 4;
static const int LED_PIN = 13;
static const uint8_t POWER_CIRCUIT_PINS[NUMBER_OF_POWER_CIRCUITS] = { 1, 2, 3, 4 };

// その他
static const int DMX_MAX = 0xFF;

struct SystemState
{
	volatile uint32_t msecCounter;
	volatile bool needInitialize;

	volatile uint8_t brightNess;
	volatile bool updateBrightness;

	volatile uint8_t currentBrightnessTableItemIndex;
	volatile uint32_t brightnessDurationCounter;

	volatile uint32_t totalSecCounter;
	volatile bool secTicked;

	volatile bool brightnessChangefinished;
	volatile bool moidsPowerFinished;

	volatile bool brightnessEndMessageShown;
	volatile bool moidsPowerEndMessageShown;

	volatile uint32_t moidsOffTimeMillisec;
	volatile uint32_t moidsOffDurationCounter;
	volatile bool needToTurnOnMoids;
	volatile bool alreadyTurnOnMoids;

	volatile uint32_t onOffTimes;
	volatile uint32_t onOffSecCounter;

	SystemState() :
			msecCounter(0), needInitialize(false), brightNess(0), updateBrightness(
					false), currentBrightnessTableItemIndex(0), brightnessDurationCounter(
					0), totalSecCounter(0), secTicked(false), brightnessChangefinished(
					false), moidsPowerFinished(false), brightnessEndMessageShown(
					false), moidsPowerEndMessageShown(false), moidsOffTimeMillisec(
					0), moidsOffDurationCounter(0), needToTurnOnMoids(false), alreadyTurnOnMoids(
					false), onOffTimes(0), onOffSecCounter(0)
	{

	}

	void initialize()
	{
		msecCounter = 0;
		needInitialize = false;
		updateBrightness = true;
		currentBrightnessTableItemIndex = 0;
		brightnessDurationCounter = 0;
		totalSecCounter = 0;
		secTicked = false;
		brightNess =
				getHumanBrightNess(
						brightnessTable[currentBrightnessTableItemIndex].initialBrightness);
		brightnessChangefinished = false;
		moidsPowerFinished = false;
		brightnessEndMessageShown = false;
		moidsPowerEndMessageShown = false;
		needToTurnOnMoids = false;
		alreadyTurnOnMoids = false;
		moidsOffDurationCounter = 0;
		onOffTimes = 0;
		onOffSecCounter = 0;

		uint32_t delayTime = (POWER_OFF_TIME_LENGTH * 1000UL);
		if (delayTime < MINIMUM_ON_OFF_ASSERT_DELAY_MSEC) {
			delayTime = MINIMUM_ON_OFF_ASSERT_DELAY_MSEC;
		}
#ifdef DEBUG
		Serial.print("init: moids delayTime =");
		Serial.println(delayTime);
#endif
		moidsOffTimeMillisec = delayTime;
		moidsOffDurationCounter = 0;
	}

	void nextBrightness()
	{
		if (brightnessChangefinished) {
			return;
		}

		currentBrightnessTableItemIndex++;

		if (currentBrightnessTableItemIndex >= NUMBER_OF_BRIGHTNESS_TABLE_ITEM) {
			brightnessChangefinished = true;
			currentBrightnessTableItemIndex--;
			return;
		}

		if (false == brightnessChangefinished) {
			brightnessDurationCounter = 0;
		}
	}
};
SystemState systemState;

void setup()
{
#ifdef DEBUG
	Serial.begin(38400);
#endif

	pinMode(POWER_CIRCUIT_MASTER_PIN, OUTPUT);
	pinMode(LED_PIN, OUTPUT);

	for (int i = 0; i < NUMBER_OF_POWER_CIRCUITS; ++i) {
		pinMode(POWER_CIRCUIT_PINS[i], OUTPUT);
	}

	DmxSimple.usePin(DMX_OUT_PIN);
	DmxSimple.maxChannel(DMX_CHANNEL);

	initializeWholeSystem();

	Timer1.initialize(1000); // 1msec
	Timer1.attachInterrupt(timerInterrupt);
}

void loop()
{
	if (systemState.needInitialize) {
		initializeWholeSystem();
		systemState.needInitialize = false;
	}

	if (systemState.needToTurnOnMoids && !systemState.alreadyTurnOnMoids) {
		systemState.alreadyTurnOnMoids = true;
		moidsPowerOnOff(true);
	}

	if (systemState.brightnessChangefinished
			&& systemState.moidsPowerFinished) {
		systemState.needInitialize = true;
	}

	if (systemState.updateBrightness) {
		DmxSimple.write(DMX_CHANNEL, systemState.brightNess);
		systemState.updateBrightness = false;
#if 0
//		Serial.print("[b] ");
//		Serial.println(systemState.brightNess);
#endif
	}

	if (systemState.secTicked) {
		systemState.secTicked = false;
#if DEBUG
		Serial.println(systemState.totalSecCounter);
#endif
	}

	if (systemState.brightnessChangefinished) {
		if (false == systemState.brightnessEndMessageShown) {
			systemState.brightnessEndMessageShown = true;
#if DEBUG
			Serial.println("[st]brightness end");
#endif
		}
	}

	if (systemState.moidsPowerFinished) {
		if (false == systemState.moidsPowerEndMessageShown) {
			systemState.moidsPowerEndMessageShown = true;
#if DEBUG
			Serial.println("[st]moids power end");
#endif
		}
	}
}

void initializeWholeSystem()
{
#if DEBUG
	Serial.println("[st]init whole");
#endif
	systemState.initialize();
	const uint8_t initialBrightness = getHumanBrightNess(
			brightnessTable[0].initialBrightness);
	DmxSimple.write(DMX_CHANNEL, initialBrightness);

	moidsPowerOnOff(false);
}

void moidsPowerOnOff(bool onOff)
{
	if (systemState.moidsPowerFinished && onOff) {
		return;
	}
	const int onOffValue = onOff ? HIGH : LOW;

	for (int i = 0; i < NUMBER_OF_POWER_CIRCUITS; ++i) {
		digitalWrite(POWER_CIRCUIT_PINS[i], onOffValue);
	}

	digitalWrite(POWER_CIRCUIT_MASTER_PIN, onOff);
	digitalWrite(LED_PIN, onOff);

#if DEBUG
	Serial.print("[st]Moids: ");
	Serial.println(onOff);
#endif

}

void timerInterrupt()
{
	systemState.msecCounter++;
	systemState.brightnessDurationCounter++;
	systemState.moidsOffDurationCounter++;

	if (systemState.msecCounter >= 1000) {
		systemState.totalSecCounter++;
		systemState.onOffSecCounter++;
		systemState.secTicked = true;
		systemState.msecCounter = 0;

		if (systemState.onOffSecCounter > MOIDS_ON_TIME_LENGTH) {
			systemState.onOffSecCounter = 0;
			systemState.onOffTimes++;

			if (false == systemState.moidsPowerFinished) {
				if (NUMBER_OF_ON_OFF_TIMES <= systemState.onOffTimes) {
					systemState.moidsPowerFinished = true;
					systemState.moidsOffDurationCounter = 0;
					systemState.alreadyTurnOnMoids = false;
					systemState.needToTurnOnMoids = false;
					systemState.moidsPowerFinished = true;
					moidsPowerOnOff(false);
					return;
				} else {
					systemState.moidsOffDurationCounter = 0;
					systemState.alreadyTurnOnMoids = false;
					systemState.needToTurnOnMoids = false;
					moidsPowerOnOff(false);
					return;
				}
			}
		}
	}

	if (systemState.moidsOffDurationCounter
			>= systemState.moidsOffTimeMillisec) {
		if (false == systemState.alreadyTurnOnMoids) {
			systemState.needToTurnOnMoids = true;
		}
	}

	// 100msecごとに明るさを変える
	if (systemState.msecCounter % 100 == 0) {
		if (false == systemState.brightnessChangefinished) {
			const uint8_t brightness =
					getHumanBrightNess(
							interpolate(systemState.brightnessDurationCounter,
									brightnessTable[systemState.currentBrightnessTableItemIndex].duration,
									brightnessTable[systemState.currentBrightnessTableItemIndex].initialBrightness,
									brightnessTable[systemState.currentBrightnessTableItemIndex].lastBrightness));

			if (systemState.brightNess != brightness) {
				systemState.brightNess = brightness;
				systemState.updateBrightness = true;
			}
		}
	}

	if (systemState.brightnessDurationCounter
			> brightnessTable[systemState.currentBrightnessTableItemIndex].duration) {
		systemState.nextBrightness();
	}
}

uint8_t getHumanBrightNess(const int& brightness)
{
	if (brightness == 0) {
		return 0;
	}

	float tmp = 0.5
			+ ((float) brightness * (float) brightness) / ((float) DMX_MAX);
	if (tmp < 1.0f) {
		tmp = 1.f;
	}

	return (uint8_t)(tmp);
}

//線形補間の公式 y = y0 + x(  (y1 - y0) / x1 )
uint8_t interpolate(uint32_t currentTime, uint32_t totalDuration,
		uint8_t startBrightness, uint8_t finalBrightness)
{
	float y0 = startBrightness;
	float y1 = finalBrightness;
	float x = currentTime;
	float x1 = totalDuration;

	float tmp = y0 + x * ((y1 - y0) / x1);

	return (uint8_t) tmp;
}

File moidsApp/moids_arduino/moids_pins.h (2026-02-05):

#pragma once

enum InputMicPin
{
    MIC_0 = 1,
    MIC_1 = 0,
    MIC_2 = 2
};

enum OutputLedPin
{
    LED_0 = 6,
    LED_1 = 10,
    LED_2 = 9
};

enum OutputRelayPin
{
    RELAY_0 = 8,
    RELAY_1 = 7,
    RELAY_2 = 4
};

static const int INPUT_MIC_PINS[3]    = {MIC_0, MIC_1, MIC_2};
static const int OUTPUT_LED_PINS[3]   = {LED_0, LED_1, LED_2};
static const int OUTPUT_RELAY_PINS[3] = {RELAY_0, RELAY_1, RELAY_2};

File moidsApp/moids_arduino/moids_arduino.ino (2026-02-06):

#include "Timer2_125usec.h"
#include "workaround.h"
#include <digitalWriteFast.h>
#include <stdint.h>
#include <util/delay.h>

#include "Moids.h"
#include "moids_constants.h"
#include "moids_pins.h"
#include "moids_sequence_mode.h"
#include "debug.h"
#include "common.h"



Moids moids[MOIDS_PER_UNIT];

bool led_state                = false;
unsigned int timerTickCounter = 0;
unsigned int moidsSec         = 0;
bool print_sec                = false;

bool should_goto_next_sequence = false;

void timerTick()
{
    timerTickCounter++;

    if (moidsMode) {
        if (timerTickCounter >= ONE_SEC_COUNT) {
            timerTickCounter = 0;
            moidsSec++;
        }

        if (moidsSec >= sequence_length) {
            moidsSec = 0;
            sequence_length++;
            currentSequence++;
            should_goto_next_sequence = true;
            return;
        }

        for (int i = 0; i < MOIDS_PER_UNIT; ++i) {
            moids[i].tick();
        }

        return;
    }


    if (pulseMode || showaMode) {
        if (timerTickCounter >= sequence_length) {
            timerTickCounter = 0;
            sequence_length++;
            currentSequence++;
            should_goto_next_sequence = true;
        }
    }
}

void setup_timer() {
  cli();
  TCCR1B = (TCCR1B & 0b11111000) | 0x01;
  TCCR0B = (TCCR0B & 0b11111000) | 0x02;
  TIMSK0 &= ~_BV(TOIE0);
  Timer2_125usec::set(ONE_SEC_COUNT, timerTick);
  Timer2_125usec::start();
  sei();
}

void setup_adc() {
  sbi(ADCSRA, ADPS2);
  cbi(ADCSRA, ADPS1);
  cbi(ADCSRA, ADPS0);
}


void setup() {


  moids_wait = pgm_read_word_near(&moids_wait_table[moids_wait_index]);
#ifdef DEBUG
  Serial.begin(115200);
  for (auto i = 0; i < 10; ++i) {
     Serial.println("Debug mode enabled");
     delay(500);
  }
#endif
  for (int i = 0; i < 13; i++) {
    pinMode(i, OUTPUT);
  }
  setup_adc();

  randomSeed(analogRead(0));

  for (int i = 0; i < MOIDS_PER_UNIT; ++i) {
    pinMode(OUTPUT_LED_PINS[i], OUTPUT);
    pinMode(OUTPUT_RELAY_PINS[i], OUTPUT);
  }

  for (int i = 0; i < MOIDS_PER_UNIT; i++) {
    moids[i].setInputMicPin(INPUT_MIC_PINS[i]);
    moids[i].setOutputLEDPin(OUTPUT_LED_PINS[i]);
    moids[i].setOutputRelayPin(OUTPUT_RELAY_PINS[i]);
    moids[i].init();

    for (int j = 0; j < MOIDS_PER_UNIT; j++) {
      if (&moids[j] != &moids[i]) {
        moids[i].registerOtherMoids(&moids[j]);
      }
    }
  }
  setup_timer();

  should_goto_next_sequence = true;
}

void loop() {
  if (should_goto_next_sequence) {
    should_goto_next_sequence = false;
    setNextSequenceData();
  }
  Serial.flush();
  if (pulseMode) {
    makePulse();
    return;
  } else if (showaMode) {
    makeShowa();
    return;
  } else if (moidsMode) {
    for (int i = 0; i < MOIDS_PER_UNIT; ++i) {
      moids[i].loop();
    }
    return;
  }
}

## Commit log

2009-05-30 add schematics and board file
    [moids2_0.1.brd, moids2_0.1.sch]
2011-03-05 [schematics]fork moid2_0.1 to make power source schem
    [moids2_0.1power.brd, moids2_0.1power.sch]
2011-03-05 [schematics]made a schem for power source
    [moids2_0.1power.brd, moids2_0.1power.sch]
2011-03-06 [schematics]correct errors, made Power PCB
    [moids2_0.1power.brd, moids2_0.1power.sch]
2011-03-09 [schematics][power]new layout
    [moids2_0.1power.brd, moids2_0.1power.sch]
2011-03-09 [schematics][power]made pcb again
    [moids2_0.1power.brd]
2011-03-22 [schematics][power]mhrs modified version
    [moids2_0.1power.brd]
2011-03-23 [schematics][power]mhrs modified version(correct gnd plane version)
    [moids2_0.1power.brd]
2011-03-23 [schematics][power]correct DRC Check
    [moids2_0.1power.brd]
2011-03-23 [schematics][power]create P-ban garbar data based on http://www.p-ban.com/gerber/eagle.html
    [moids2_0.1power.brd]
2012-01-28 add power schematics and pcb
    [moids2_0.1power.brd, moids2_0.1power.sch]
2012-01-29 modify folder structure, modify some files for Arduino 1.0
2012-03-08 modify README and TODO, delete non-ascii files, add pdfs for schematics
2013-01-17 add power and light control feature
2019-07-11 add board
2019-07-11 add power board pdf
2025-11-14 obsolete and move old eagle files
    [moids2_0.1.brd, moids2_0.1.sch, moids2_0.1power.brd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]
2025-11-14 convert to the latest(and last?) eagle project
    [moids2_0.1.brd, moids2_0.1.sch, moids2_0.1power.brd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]
2025-11-14 convert latest eagle file to kicad
    [moids2_0.1.kicad_pcb, moids2_0.1.kicad_sch, moids2_0.1power.kicad_pcb]
2025-11-14 add power source 2025(WIP)
    [2025_power-CuBottom.gbr, 2025_power-CuTop.gbr, 2025_power-EdgeCuts.gbr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]
2025-11-14 reorganize shchematics folder
    [moids2_0.1.brd, moids2_0.1.sch, moids2_0.1power.brd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]
2025-11-14 WIP: compile available with arduino 2025(NOT WORKING!)
    [moids_arduino.ino]
2025-11-16 update software, confirm working! correct wrong timer counter max for 1sec
    [moids_arduino.ino]
2025-12-27 2025 power revised
    [2025_power-CuBottom.gbr, 2025_power-CuTop.gbr, 2025_power-EdgeCuts.gbr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]
2026-02-06 [WIP] remove unpredictable timer behavior
